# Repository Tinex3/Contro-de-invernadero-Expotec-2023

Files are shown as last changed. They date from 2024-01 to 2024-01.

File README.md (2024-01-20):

# Sistema de Control de Invernadero Expotec 2023

## Descripción

Este proyecto es un sistema de control de invernadero basado en control On-off. Utiliza tecnologías como LabVIEW 2013 y Arduino Firmware para proporcionar un control eficiente de las condiciones ambientales dentro del invernadero. La comunicación entre LabVIEW y Arduino se realiza a través de un puerto serial. Los valores de temperatura se pueden ajustar directamente en el código C++.

## Características Clave

- Control de temperatura y humedad en tiempo real.
- Interfaz de usuario amigable diseñada con LabVIEW 2013.
- Integración con sensores, incluyendo el sensor LM35DZ, DHT11 y el sensor de humedad YI-38, para un control preciso.
- Configuración personalizada de umbrales y alarmas a través del código de arduino.
- Control de dispositivos, como bomba y ventiladores, para mantener las condiciones ideales.

## Requisitos de Instalación

Para ejecutar este proyecto, necesitas:

- LabVIEW 2013.
- Arduino IDE (versión X.X.X)
- Hardware compatible con Arduino (sensores lm35DZ, DHT11 y sensor de humedad YI-38).
- Conexión física entre tu computadora y el Arduino a través de un puerto serial.
- NI Visa (versión 5.3) para la comunicación con LabVIEW.

## Instrucciones de Uso

1. Descarga y ejecuta la última versión del software.
2. Conecta los sensores y actuadores Arduino a tu invernadero.
3. Asegúrate de que la comunicación por puerto serial esté establecida entre LabVIEW y Arduino.
4. Abre la interfaz de usuario de LabVIEW 2013.
5. Configura los umbrales de temperatura y humedad directamente en el código CPP.
6. Inicia el sistema de control y monitorea las condiciones ambientales en tiempo real.
7. Controla dispositivos como la bomba y los ventiladores según sea necesario.

## Ejemplos y Escenarios de Uso

- Controla la temperatura y humedad en tu invernadero para el cultivo de plantas sensibles.
- Automatiza el riego y la ventilación en función de las condiciones actuales.
- Recibe alertas cuando se detecten condiciones fuera de los umbrales establecidos.

## Contribución y Desarrollo

Agradecemos las contribuciones de la comunidad. Si deseas contribuir a este proyecto, sigue los pasos a continuación:

1. Haz un fork del repositorio.
2. Crea una nueva rama para tu contribución.
3. Realiza los cambios y pruebas necesarios.
4. Envía una solicitud de extracción (pull request).

## Licencia

Este proyecto está bajo la [Licencia Apache 2.0](https://www.apache.org/licenses/LICENSE-2.0).

## Contacto y Soporte

Si tienes preguntas o necesitas asistencia, puedes contactarme en `b.riquelme.gomez@gmail.com`.

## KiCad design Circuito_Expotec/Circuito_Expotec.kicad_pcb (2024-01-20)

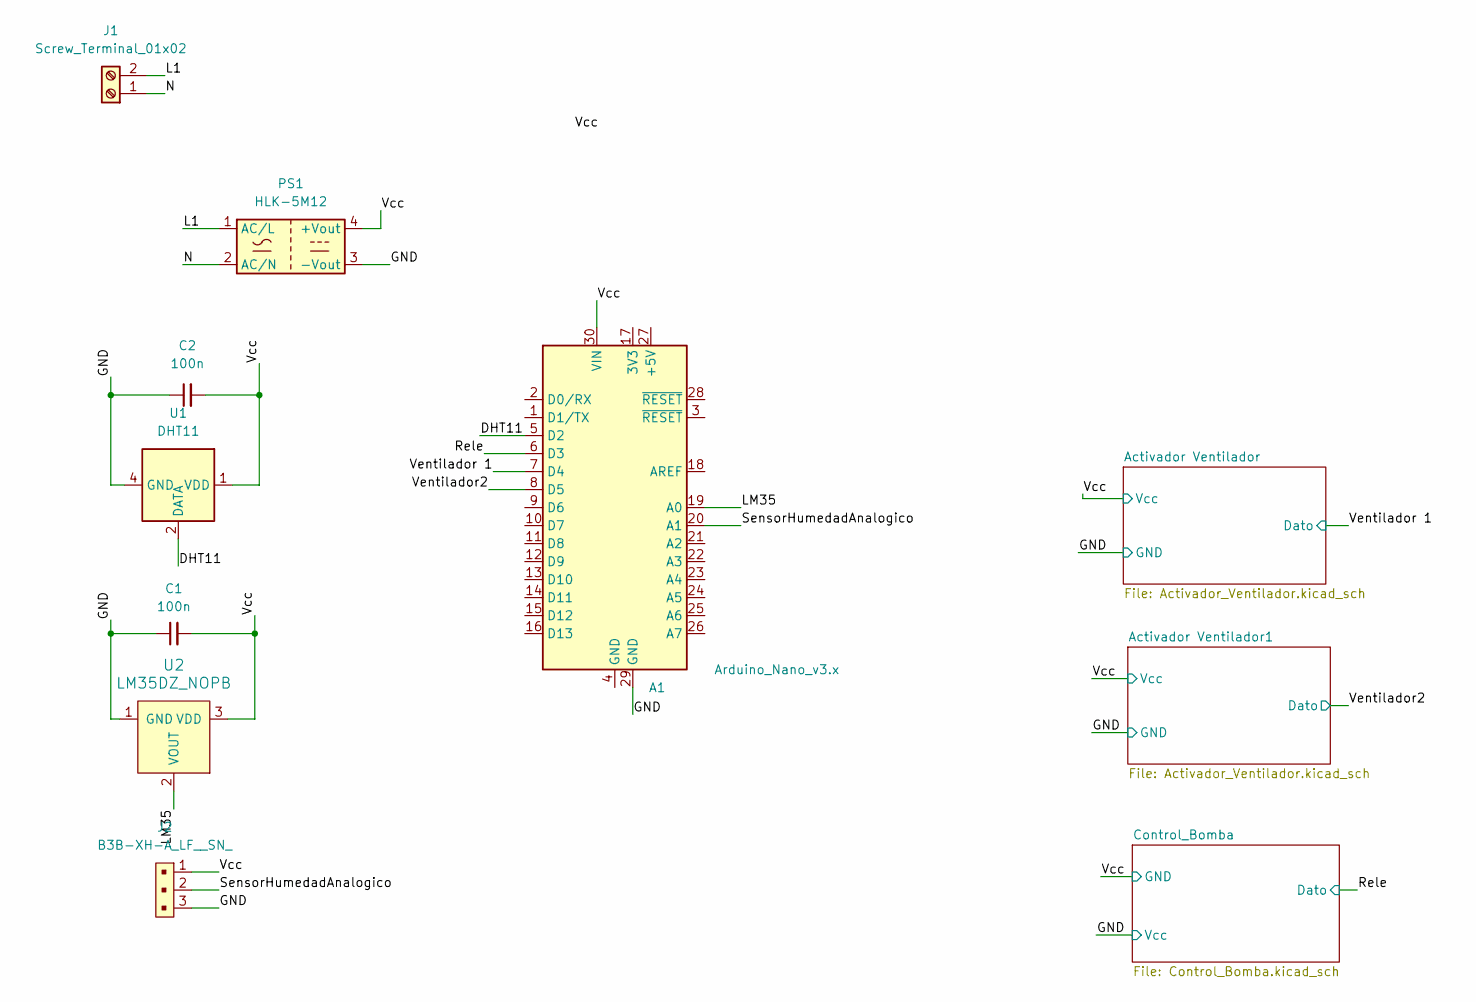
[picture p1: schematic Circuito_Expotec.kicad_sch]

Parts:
A1: Arduino_Nano_v3.x; Arduino_Nano
C1, C2: 100n; C_Disc_D6.0mm_W2.5mm_P5.00mm
J1: Screw_Terminal_01x02; TerminalBlock_MetzConnect_Type011_RT05502HBWC_1x02_P5.00mm_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
J2: B3B-XH-A_LF__SN_; PinHeader_1x3_P2.5mm_Drill1.1mm; MPN B3B-XH-A(LF)(SN); Digi-Key_PN 455-2248-ND
PS1: HLK-5M12; Converter_ACDC_HiLink_HLK-5Mxx
U1: DHT11; Aosong_DHT11_5.5x12.0_P2.54mm
U2: LM35DZ_NOPB; TO-92-3; MPN LM35DZ/NOPB; Digi-Key_PN LM35DZ/NOPB-ND

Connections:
/DHT11: A1.5 (D2), U1.2 (DATA)
/GND: A1.29 (GND), C1.1, C2.1, J2.3, PS1.3 (-Vout), U1.4 (GND), U2.1 (GND); also elsewhere on the board
/L1: J1.2, PS1.1 (AC/L)
/LM35: A1.19 (A0), U2.2 (VOUT)
/N: J1.1, PS1.2 (AC/N)
/Rele: A1.6 (D3); also elsewhere on the board
/SensorHumedadAnalogico: A1.20 (A1), J2.2
/Vcc: A1.30 (VIN), C1.2, C2.2, J2.1, PS1.4 (+Vout), U1.1 (VDD), U2.3 (VDD); also elsewhere on the board
/Ventilador2: A1.8 (D5); also elsewhere on the board
/Ventilador 1: A1.7 (D4); also elsewhere on the board

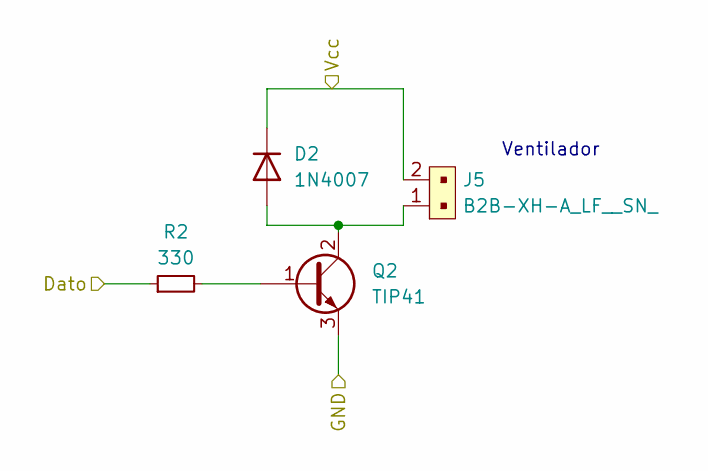
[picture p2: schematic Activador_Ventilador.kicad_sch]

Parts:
D2: 1N4007; D_DO-41_SOD81_P10.16mm_Horizontal
J5: B2B-XH-A_LF__SN_; PinHeader_1x2_P2.5mm_Drill1.1mm; MPN B2B-XH-A(LF)(SN); Digi-Key_PN 455-2247-ND
Q2: TIP41; TO-220-3_Vertical
R2: 330; R_1206_3216Metric

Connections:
/GND: Q2.3 (E); also elsewhere on the board
/Vcc: D2.1 (K), J5.2; also elsewhere on the board
/Ventilador2: R2.1; also elsewhere on the board
unnamed: D2.2 (A), J5.1, Q2.2 (C)
unnamed: Q2.1 (B), R2.2

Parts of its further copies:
D1: 1N4007; D_DO-41_SOD81_P10.16mm_Horizontal
J3: B2B-XH-A_LF__SN_; PinHeader_1x2_P2.5mm_Drill1.1mm; MPN B2B-XH-A(LF)(SN); Digi-Key_PN 455-2247-ND
Q1: TIP41; TO-220-3_Vertical
R1: 330; R_1206_3216Metric

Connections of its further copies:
/GND: Q1.3 (E); also elsewhere on the board
/Vcc: D1.1 (K), J3.2; also elsewhere on the board
/Ventilador 1: R1.1; also elsewhere on the board
unnamed: D1.2 (A), J3.1, Q1.2 (C)
unnamed: Q1.1 (B), R1.2

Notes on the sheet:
Ventilador

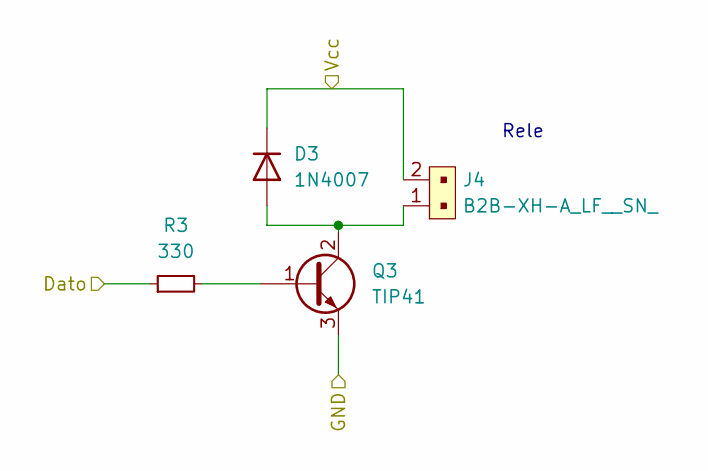
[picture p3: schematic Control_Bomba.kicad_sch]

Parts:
D3: 1N4007; D_DO-41_SOD81_P10.16mm_Horizontal
J4: B2B-XH-A_LF__SN_; PinHeader_1x2_P2.5mm_Drill1.1mm; MPN B2B-XH-A(LF)(SN); Digi-Key_PN 455-2247-ND
Q3: TIP41; TO-220-3_Vertical
R3: 330; R_1206_3216Metric

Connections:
/GND: D3.1 (K), J4.2; also elsewhere on the board
/Rele: R3.1; also elsewhere on the board
/Vcc: Q3.3 (E); also elsewhere on the board
unnamed: D3.2 (A), J4.1, Q3.2 (C)
unnamed: Q3.1 (B), R3.2

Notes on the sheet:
Rele

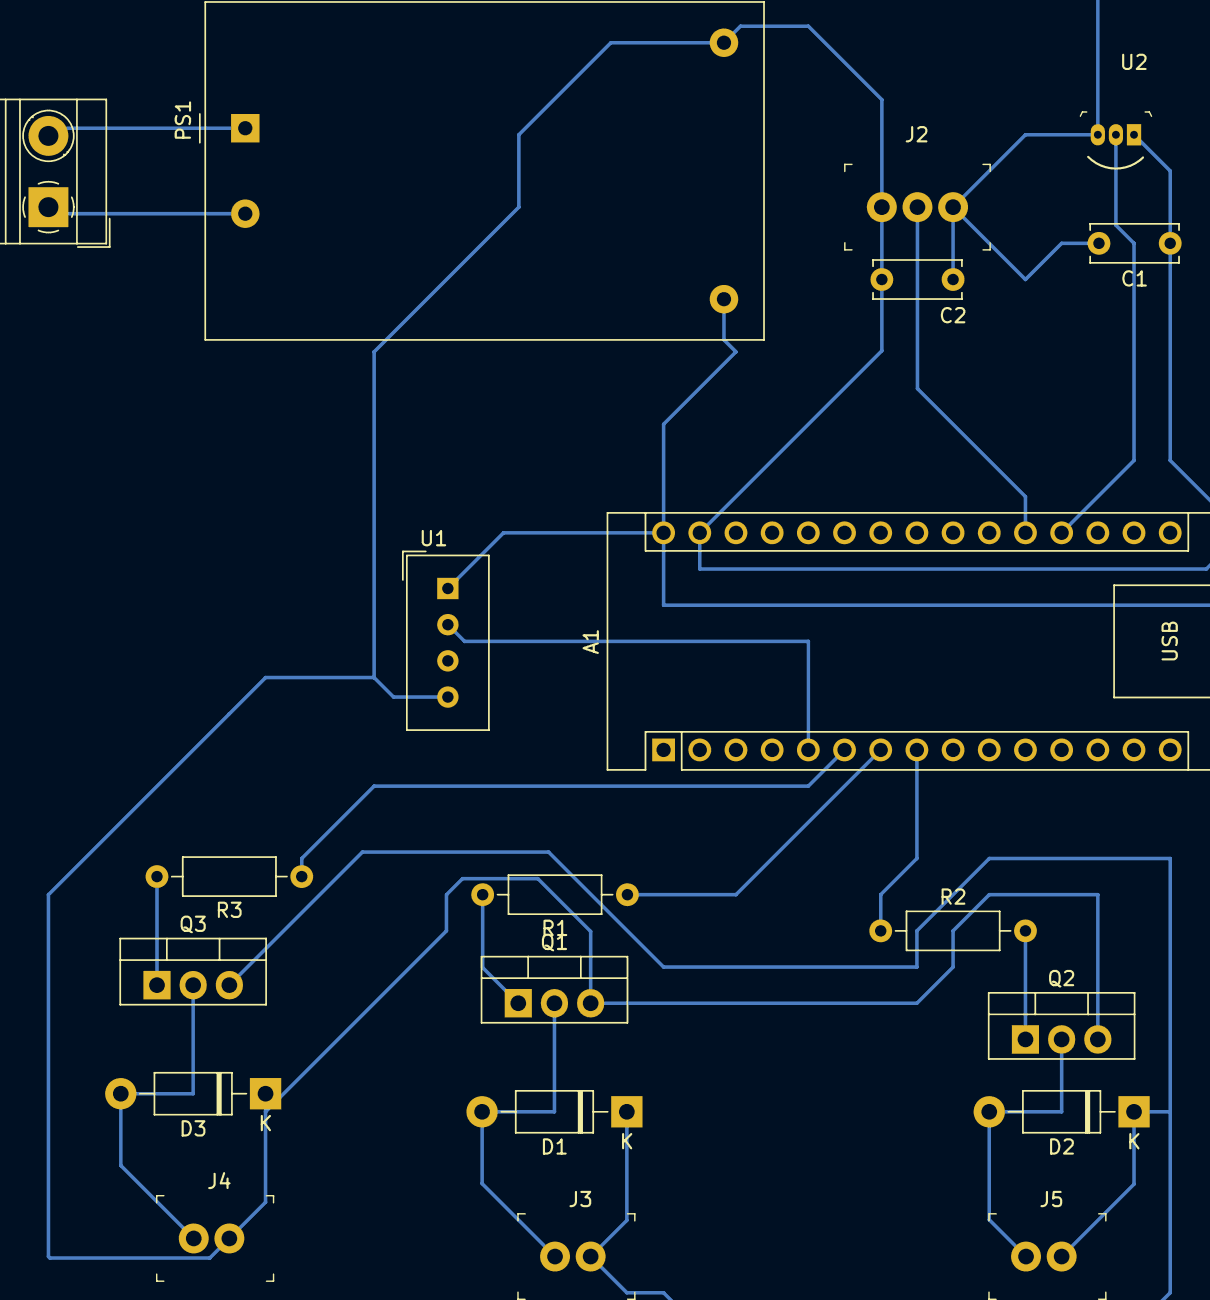
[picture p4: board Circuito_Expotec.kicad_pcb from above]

Board: 2 copper layers, 20 parts (0 on the bottom side), 16 nets.

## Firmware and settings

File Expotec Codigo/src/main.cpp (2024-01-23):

#include <Arduino.h>
#include <DHT.h>

#define DHTPIN 2
#define DHTTYPE DHT11

#define BAUDIOS 115200
#define TIEMPO_ACCION 5000 // Tiempo de ejecución de la acción en milisegundos (por ejemplo, 5 segundos)
#define INTERVALO_LECTURA 500 // Intervalo de lectura en milisegundos (150 ms en este caso)



typedef struct Controldeinvernadero{
    uint16_t LM35 = A0;
    uint16_t Lectura_En_Tierra = A1;
    uint16_t BOMBA = 3;
    uint16_t VENTILADOR1 = 4;
    uint16_t VENTILADOR2 =5;
}Control_Agua;
Control_Agua Maqueta;



typedef struct Datos
{
    uint16_t LecturaLM35;
    uint16_t ValorTierra;
    uint16_t HumedadDHT;
    uint16_t TemperaturaDHT;

}Lecturas;
Lecturas Sensores;





DHT dht(DHTPIN, DHTTYPE);

enum Estado {
    ESPERANDO_COMANDO,
    EJECUTANDO_ACCION
};

Estado estado = ESPERANDO_COMANDO;
unsigned long tiempoInicioAccion = 0;
unsigned long tiempoUltimaLectura = 0;

void lecturadedatos(Lecturas *Sensores,Control_Agua *Perifericos);
void ejecutarComando(char comando);
void activarBomba(Control_Agua *Maqueta);
void activarVentilador1(Control_Agua &Perifericos);
void activarVentilador2(Control_Agua &Perifericos);
void detenerSalidas(Control_Agua &Perifericos);
void Init_maqueta(Control_Agua &Perifericos);
void Imprimir(Lecturas *Sensores);


void setup() {
    Serial.begin(BAUDIOS);
    dht.begin();
    Init_maqueta(Maqueta);

}

void Init_maqueta(Control_Agua &Perifericos){
    pinMode(Perifericos.LM35,INPUT);
    pinMode(Perifericos.Lectura_En_Tierra, INPUT);
    pinMode(Perifericos.BOMBA, OUTPUT);
    pinMode(Perifericos.VENTILADOR1,OUTPUT);
    pinMode(Perifericos.VENTILADOR2,OUTPUT);
}

void loop() {
    unsigned long tiempoActual = millis();

    // Realizar lectura y enviar datos cada 150 ms
    if (tiempoActual - tiempoUltimaLectura >= INTERVALO_LECTURA) {
        lecturadedatos( &Sensores,&Maqueta);
        Imprimir(&Sensores);
        tiempoUltimaLectura = tiempoActual;
    }

    switch (estado) {
        case ESPERANDO_COMANDO:
            if (Serial.available()) {
                char var = Serial.read();
                ejecutarComando(var);
            }
            break;
        case EJECUTANDO_ACCION:
            if (millis() - tiempoInicioAccion >= TIEMPO_ACCION) {
                detenerSalidas(Maqueta);
                estado = ESPERANDO_COMANDO;
            }
            break;
    }
}

void ejecutarComando(char comando) {
    switch (comando) {
        case 'A':
            activarBomba(&Maqueta);
            break;
        case 'B':
            activarVentilador1(Maqueta);
            break;
        case 'C':
            activarVentilador2(Maqueta);
            break;
        case 'D':
            activarBomba(Maqueta);
            activarVentilador1(Maqueta);
            activarVentilador2(Maqueta);
            break;
        // Agrega más casos de comandos si es necesario
    }
}

void activarBomba(Control_Agua &Perifericos){
    digitalWrite(Perifericos.BOMBA, HIGH);
    tiempoInicioAccion = millis();
    estado = EJECUTANDO_ACCION;
}

void activarVentilador1(Control_Agua &Perifericos) {
    digitalWrite(Perifericos.VENTILADOR1, HIGH);
    tiempoInicioAccion = millis();
    estado = EJECUTANDO_ACCION;
}

void activarVentilador2(Control_Agua &Perifericos) {
    digitalWrite(Perifericos.VENTILADOR2, HIGH);
    tiempoInicioAccion = millis();
    estado = EJECUTANDO_ACCION;
}

void detenerSalidas(Control_Agua &Perifericos) {
    digitalWrite(Perifericos.BOMBA, LOW);
    digitalWrite(Perifericos.VENTILADOR1, LOW);
    digitalWrite(Perifericos.VENTILADOR2, LOW);
}

void lecturadedatos(Lecturas *Sensores, Control_Agua *Maqueta) {
    // Lógica para leer datos de los sensores y enviarlos por el puerto serie
    int valorLM35 = analogRead(Maqueta->LM35);
    Sensores->LecturaLM35 = 10000+((5*valorLM35*100)/1024); // Convertir el valor a temperatura en grados Celsius

    int valorTierra = 10000+analogRead(Maqueta->Lectura_En_Tierra);
    Sensores->ValorTierra = valorTierra;
    Sensores->HumedadDHT = 10000+dht.readHumidity();
    Sensores->TemperaturaDHT = 10000+dht.readTemperature();
}
void Imprimir(Lecturas *Sensores){
    // Enviar datos por Serial (puedes modificar este formato según tus necesidades)
    Serial.print(Sensores->ValorTierra);
    Serial.print("\t");
    Serial.print(Sensores->LecturaLM35);
    Serial.print("\t");
    Serial.print(Sensores->HumedadDHT);
    Serial.print("\t");
    Serial.print(Sensores->TemperaturaDHT);
    Serial.print("\t"); 
}

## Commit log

2024-01-20 Se corrigen nombre de sensor de temperatura
2024-01-20 Se agrega extructura de datos
2024-01-20 Se crea circuito en kicad
    [Activador_Ventilador.kicad_sch, Circuito_Expotec.kicad_pcb, Circuito_Expotec.kicad_sch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]
